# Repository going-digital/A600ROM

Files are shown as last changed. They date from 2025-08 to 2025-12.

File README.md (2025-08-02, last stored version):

# A600ROM
Flash ROM Kickstart replacement for the Amiga A600

## This project is in development and currently untested.

This project replaces the Kickstart ROM in the Amiga A600 with a 2M x 16 Flash chip. This allows 4 x 512kB or 2 x 1MB Flash banks.

Initial programming of the first Kickstart must be done with a programmer. But after that, programming can be done in-circuit from the Amiga.

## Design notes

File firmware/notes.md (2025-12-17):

# Imagedef

See Raspberry Pi 5.9.5 which gives minimal image_def. Should be able to use that to build a minimal image.

Microcontroller is Cortex-M33

pico-sdk/src/rp2_common/pico_crt0/embedded_start_block.inc.S
pico-sdk/src/rp2_common/pico_crt0/embedded_end_block.inc.S
pico-sdk/src/rp2_common/pico_crt0/rp2350

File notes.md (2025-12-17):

# Notes

## 16 bit mode

| Function | Socket pin | GPIO | Notes |
| --- | --- | --- | ----- |
| D15-D0 | 30,28,26,24,21,19,17,15,29,27,25,23,20,18,16,14 | GPIO15-0  |
| A18-A1 | 2,33-41,3-10 | GPIO33-16 |
| nBYTE | 32 | GPIO35 | High  |
| nCS | 11 | GPIO34 |
| nOE | 13 | GPIO36 |

### Convert address

| Image address bit | GPIO | SRAM bit |
| --- | --- | --- |
| 1 | GPIO33 | 18 |
| 2 | GPIO32 | 17 |
| 3 | GPIO31 | 16 |
| 4 | GPIO30 | 15 |
| 5 | GPIO29 | 14 |
| 6 | GPIO28 | 13 |
| 7 | GPIO27 | 12 |
| 8 | GPIO26 | 11 |
| 9 | GPIO24 | 10 |
| 10 | GPIO23 | 9 |
| 11 | GPIO22 | 8 |
| 12 | GPIO21 | 7 |
| 13 | GPIO20 | 6 |
| 14 | GPIO19 | 5 |
| 15 | GPIO18 | 4 |
| 16 | GPIO17 | 3 |
| 17 | GPIO16 | 2 |
| 18 | GPIO25 | 1 |

### Convert data

| Data bit | SRAM bit | Shift |
| --- | --- |-|
| 14 | 7 |-7
| 12 | 6 |-6
| 10 | 5 |-5
| 7 | 2 |-5
| 8 | 4 |-4
| 2 | 1 |-1
| 4 | 3 |-1
| 0 | 0 |0
| 15 | 15 |0
| 13 | 14 |1
| 11 | 13 |2
| 9 | 12 |3
| 6 | 10 |4
| 3 | 9 |6
| 5 | 11 |6
| 1 | 8 |7

### CS Output enable
```asm
inactive:
    mov pindirs, null
    mov x, pins
    jmp x--, inactive
active:
    mov pindirs, ~null
    mov x, pins
    jmp !x, active
```

### PIO Address capture
```asm
    in y, 13 [1]
    in pins, 18
    in y, 1
```

### DMA_1 Address forwarder
#### Purpose
Forward addresses from PIO to DMA_2 READ_ADDR register
#### Configuration
| | |
| --- | --- |
| Trigger | PIO_ADDR TX FIFO DREQ |
| Read from | PIO_ADDR RX FIFO (alias for TX) |
| Write to | DMA_2 READADDR (CHx_READ_ADDR)  |
| Transfer size  | 32 bit word |
| Transfer count | 1 |
| Chain to | DMA_2 |

### PIO Data fetch
```asm
    out pins, 16
```

### DMA_2 ROM Data fetch
#### Purpose
Read byte from ROM table and write to GPIO
#### Configuration
| | |
| --- | --- |
| Trigger | Chained from DMA_1 |
| Read from | Address set dynamically by DMA_1 |
| Write to | GPIO_OUT register |
| Transfer size  | 16 bit word |
| Transfer count | 1 |

## 8 bit mode

| Function | Socket pin | GPIO | Notes |
| --- | --- | --- | ----- |
| D7-D0 | 29,27,25,23,20,18,16,14 | GPIO7-0 |
| A18-A0 | 2,33-41,3-10,30 | GPIO33-15 |
| nBYTE | 32 | GPIO35 | Low |
| nCS | 11 | GPIO34 |
| nOE | 13 | GPIO36 |

### CS Output enable

As above

### PIO Address capture

```asm
    in y, 13 [2]
    in pins, 19
```

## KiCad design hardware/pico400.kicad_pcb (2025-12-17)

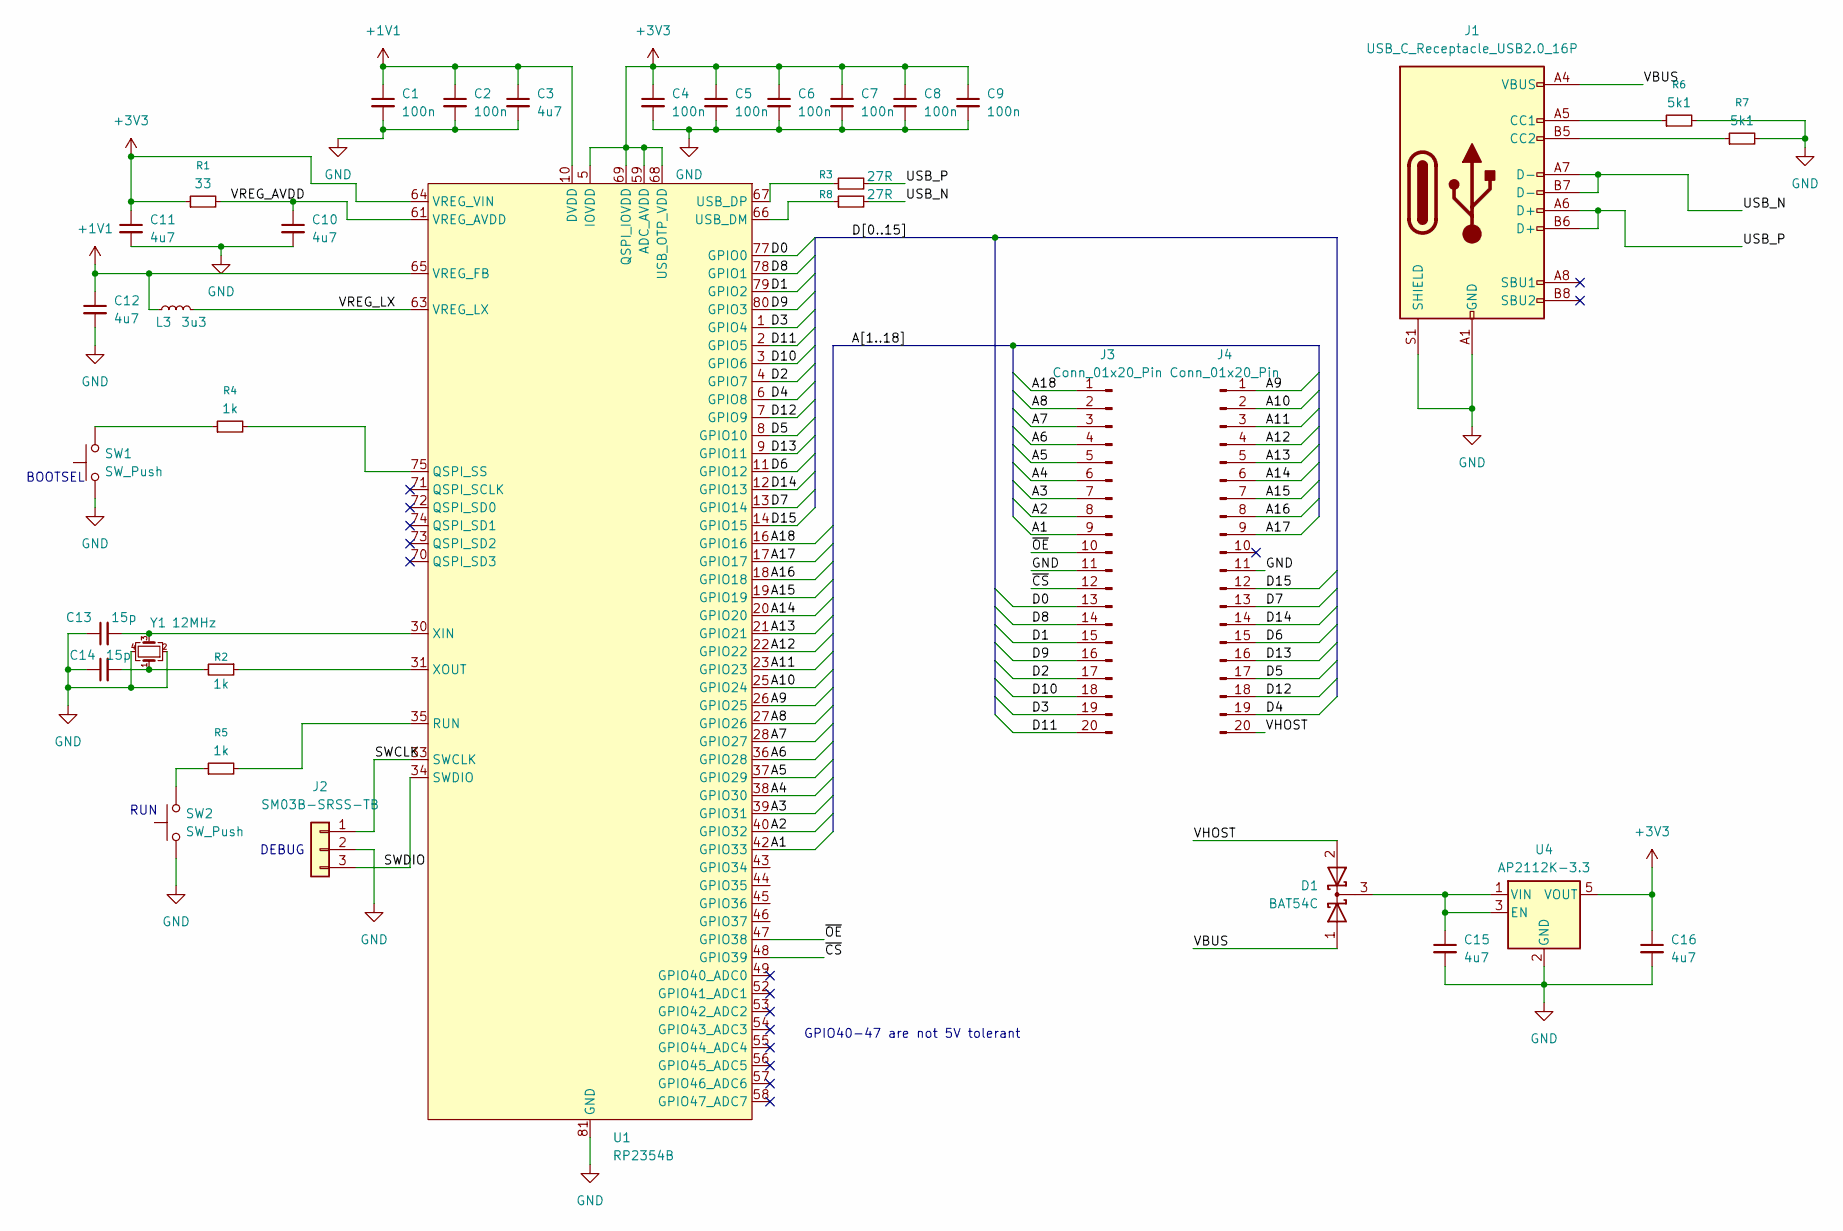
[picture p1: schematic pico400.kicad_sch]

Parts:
C1, C2, C4, C5, C6, C7, C8, C9: 100n; C_0402_1005Metric
C3, C10, C11, C12, C15, C16: 4u7; C_0402_1005Metric
C13, C14: 15p; C_0402_1005Metric
D1: BAT54C; SOT-23
J1: USB_C_Receptacle_USB2.0_16P; USB_C_Receptacle_HCTL_HC-TYPE-C-16P-01A; JLCPCB Part # C2765186
J2: SM03B-SRSS-TB; JST_SH_SM03B-SRSS-TB_1x03-1MP_P1.00mm_Horizontal
J3, J4: Conn_01x20_Pin; PinHeader_1x20_P2.54mm_Vertical
L3: 3u3; L_0805_2012Metric
R1: 33; R_0402_1005Metric
R2, R4, R5: 1k; R_0402_1005Metric
R3, R8: 27R; R_0402_1005Metric
R6, R7: 5k1; R_0402_1005Metric
SW1, SW2: SW_Push; SW_Tactile_SPST_NO_Straight_CK_PTS636Sx25SMTRLFS
U1: RP2354B; QFN-80-1EP_10x10mm_P0.4mm_EP3.4x3.4mm_ThermalVias; JLCPCB Part # C39843328
U4: AP2112K-3.3; SOT-23-5
Y1: 12MHz; Crystal_SMD_0603-4Pin_6.0x3.5mm

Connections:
+1V1: C1.1, C2.1, C3.1, C12.1, L3.1, U1.10 (DVDD), U1.32 (DVDD), U1.51 (DVDD), U1.65 (VREG_FB)
+3V3: C4.1, C5.1, C6.1, C7.1, C8.1, C9.1, C11.1, C16.1, R1.1, U1.5 (IOVDD), U1.15 (IOVDD), U1.24 (IOVDD), U1.29 (IOVDD), U1.41 (IOVDD), U1.50 (IOVDD), U1.59 (ADC_AVDD), U1.60 (IOVDD), U1.64 (VREG_VIN), U1.68 (USB_OTP_VDD), U1.69 (QSPI_IOVDD), U1.76 (IOVDD), U4.5 (VOUT)
/A1: J3.9, U1.42 (GPIO33)
/A2: J3.8, U1.40 (GPIO32)
/A3: J3.7, U1.39 (GPIO31)
/A4: J3.6, U1.38 (GPIO30)
/A5: J3.5, U1.37 (GPIO29)
/A6: J3.4, U1.36 (GPIO28)
/A7: J3.3, U1.28 (GPIO27)
/A8: J3.2, U1.27 (GPIO26)
/A9: J4.1, U1.26 (GPIO25)
/A10: J4.2, U1.25 (GPIO24)
/A11: J4.3, U1.23 (GPIO23)
/A12: J4.4, U1.22 (GPIO22)
/A13: J4.5, U1.21 (GPIO21)
/A14: J4.6, U1.20 (GPIO20)
/A15: J4.7, U1.19 (GPIO19)
/A16: J4.8, U1.18 (GPIO18)
/A17: J4.9, U1.17 (GPIO17)
/A18: J3.1, U1.16 (GPIO16)
/D0: J3.13, U1.77 (GPIO0)
/D1: J3.15, U1.79 (GPIO2)
/D2: J3.17, U1.4 (GPIO7)
/D3: J3.19, U1.1 (GPIO4)
/D4: J4.19, U1.6 (GPIO8)
/D5: J4.17, U1.8 (GPIO10)
/D6: J4.15, U1.11 (GPIO12)
/D7: J4.13, U1.13 (GPIO14)
/D8: J3.14, U1.78 (GPIO1)
/D9: J3.16, U1.80 (GPIO3)
/D10: J3.18, U1.3 (GPIO6)
/D11: J3.20, U1.2 (GPIO5)
/D12: J4.18, U1.7 (GPIO9)
/D13: J4.16, U1.9 (GPIO11)
/D14: J4.14, U1.12 (GPIO13)
/D15: J4.12, U1.14 (GPIO15)
/SWCLK: J2.1, U1.33 (SWCLK)
/SWDIO: J2.3, U1.34 (SWDIO)
/USB_N: J1.A7 (D-), J1.B7 (D-), R8.2
/USB_P: J1.A6 (D+), J1.B6 (D+), R3.2
/VBUS: D1.1 (A), J1.A4 (VBUS), J1.A9 (VBUS), J1.B4 (VBUS), J1.B9 (VBUS)
/VHOST: D1.2 (A), J4.20
/VREG_AVDD: C10.1, R1.2, U1.61 (VREG_AVDD)
/VREG_LX: L3.2, U1.63 (VREG_LX)
/~CS: J3.12, U1.48 (GPIO39)
/~OE: J3.10, U1.47 (GPIO38)
GND: C1.2, C2.2, C3.2, C4.2, C5.2, C6.2, C7.2, C8.2, C9.2, C10.2, C11.2, C12.2, C13.1, C14.1, C15.2, C16.2, J1.A1 (GND), J1.A12 (GND), J1.B1 (GND), J1.B12 (GND), J1.S1 (SHIELD), J2.2, J3.11, J4.11, R6.2, R7.2, SW1.1, SW2.1, U1.62 (VREG_PGND), U1.81 (GND), U4.2 (GND), Y1.2, Y1.4
unnamed: C14.2, R2.2, Y1.1
unnamed: C15.1, D1.3 (K), U4.1 (VIN), U4.3 (EN)
unnamed: J1.A5 (CC1), R6.1
unnamed: J1.B5 (CC2), R7.1
unnamed: R4.1, SW1.2
unnamed: R5.1, SW2.2
unnamed: R4.2, U1.75 (QSPI_SS)
unnamed: R5.2, U1.35 (RUN)
unnamed: R8.1, U1.66 (USB_DM)
unnamed: R3.1, U1.67 (USB_DP)
unnamed: C13.2, U1.30 (XIN), Y1.3
unnamed: R2.1, U1.31 (XOUT)

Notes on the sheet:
BOOTSEL
RUN
DEBUG
GPIO40-47 are not 5V tolerant

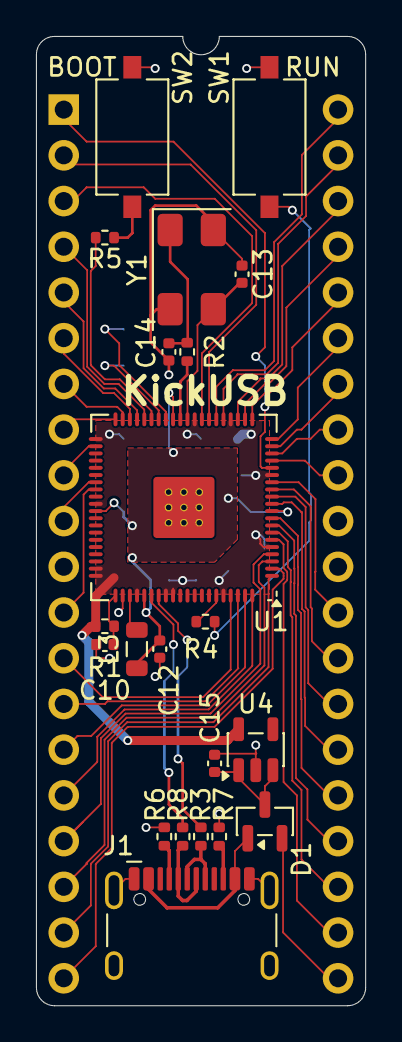
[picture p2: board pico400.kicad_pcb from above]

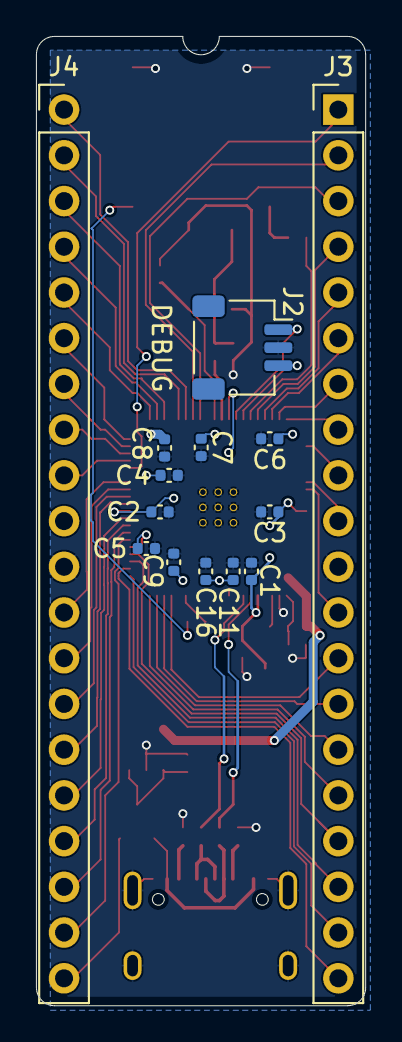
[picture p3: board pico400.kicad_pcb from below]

Board: 2 copper layers, 18.3 x 53.8 mm, 35 parts (14 on the bottom side), 59 nets.

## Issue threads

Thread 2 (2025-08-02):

Pins damage motherboard sockets

going-digital, 2025-08-02:
Square header pins cause socket damage. Find a better alternative.

going-digital, 2025-08-02:
Possible candidate [Samtec TS-132-T-A](https://mou.sr/4m1HPI6)

going-digital, 2025-08-03:
Better candidate - 2 x [Harwin D01-9973242](https://www.harwin.com/products/D01-9973242) for top ROM socket (cut to length 21, with pins sanded flat to fit SMD pad), and 2 x [Harwin D01-9923246](https://www.harwin.com/products/D01-9923246) for bottom header. Again, cut to size with pins flattened.

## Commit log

2025-08-03 Gayle hat
    Add hat. Partially unrouted.
    [A600ROM.kicad_sch]
2025-08-04 Add connectors
    [A600ROM.kicad_pcb, A600ROM.kicad_sch, d01-9923246.stp]
